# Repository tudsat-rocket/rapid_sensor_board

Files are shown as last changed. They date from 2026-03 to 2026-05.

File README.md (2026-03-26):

# Rapid Sensor Board
this module is meant to be a general-purpose amplifier which is going to be used for all analogue sensors which will be in the rocket, those include the WIKA pressure sensors as well as the fancy-fins strain gauges.

## Description
The main function of the module is to amplify signals with low voltage levels that are too small to be useful for our ADCs. Therefore the board has two sides with solder pads, one to connect to the IO board and one to connect to a sensor. The layout is designed in a way, that the sensor side is compatible with the WIKA TPR-Flex PCBs.

## Features
* Selectable gain (1-1000) -> the selection of RG1 will determine the gain (G = 1 + 49,4kOhm/RG)
* selectable offset -> output offset can either be 0V or Vcc/2
* Breakaway mounting holes
## Connections
### To IO-Board:
Connects the amplifier module with the IO-Board with the following pins:
* u+  ->  positive supply voltage (3-36V)
* u-  ->  gnd as "neg" supply voltage (only use in single supply mode) | reference for the output signal.
* o+  ->  amplified signal, references gnd (u-)
* ref  ->  selected reference signal (0V or Vcc/2) can be used to get additional information (e.g. detect noise on supply line(?))

### To sensor:
Connects the amplifier module with the Sensor with the following pins:
* u+  -> positive supply voltage (filtered supply voltage)
* u-  -> neg. supply voltage (gnd)
* s+  -> positive signal
* s-  -> negative signal

## User guideline:
The Gain resistor (RG1) must be chosen in a way that the expected maximum amplified voltage is lower than 4.85V (5V - 0.15V) and the expected minimum amplified voltage is higher than 0.1V if a smaller (or negative) output voltage is expected the solder jumper for the reference voltage needs to be connected to 3 to set an output shift.
Only if the connected sensor is expected to output a signal which exclusively results in an output signal that is in the above given values, can the reference solder jumper be set to 1.

The above-given adjustments are necessary as the IO module is only able to read values between 0V and 5V. A higher Input voltage can be used if the connected sensor needs a supply voltage which exceeds 5V. The amplified signal then still needs to be smaller than the given 4.85V.

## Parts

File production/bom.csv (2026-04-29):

Designator | Footprint | Quantity | Value | LCSC Part #
C1 | 0402 | 1 | 10u | C15525
C10, C9 | 0402 | 2 | 1n | C1523
C14, C3, C4 | 0402 | 3 | 100n | C1525
C15, C16 | 0402 | 2 | 1u | C52923
C2 | 0402 | 1 | 4u7 | C23733
C7, C8 | 0402 | 2 | 10n | C15195
D1 | D_SOD-523 | 1 | 1SS424 | C6657698
D2, D3, D7, D8 | D_SOD-523 | 4 | ESD5Z36 | C20933
D4 | D_SOD-523 | 1 | ESD5Zxx | C20933
FB1, FB2 | 0402 | 2 | 120R | C76891
IC1 | WSON-8-1EP_3x3mm_P0.5mm_EP1.2x2mm | 1 | INA826AID | C2870890
J3 | R_Axial_DIN0204_L3.6mm_D1.6mm_P1.90mm_Vertical | 1 | Conn_01x02_Socket
J5 | PinHeader_1x04_P1.27mm_Vertical | 1 | Conn_01x04_Socket
JP1 | SolderJumper-3_P1.3mm_Open_RoundedPad1.0x1.5mm | 1 | ADR1
JP2 | SolderJumper-3_P1.3mm_Open_RoundedPad1.0x1.5mm | 1 | ADR0
JP3 | SolderJumper-3_P1.3mm_Open_Pad1.0x1.5mm | 1 | SolderJumper_3_Open
R1, R2 | 0402 | 2 | 47k | C25792
R10, R9 | 0402 | 2 | 100 | C25076
R5, R6 | 0402 | 2 | 10k | C25744
TP1 | TestPoint_Pad_D1.5mm | 1 | TestPoint
U2 | SOT-23-5 | 1 | MCP6001-OT | C116490
U3 | SOT-23-5 | 1 | MIC5504-3.3YM5 | C3021093
U4 | VSSOP-8_3x3mm_P0.65mm | 1 | ADC101C021CIMM | C1543337

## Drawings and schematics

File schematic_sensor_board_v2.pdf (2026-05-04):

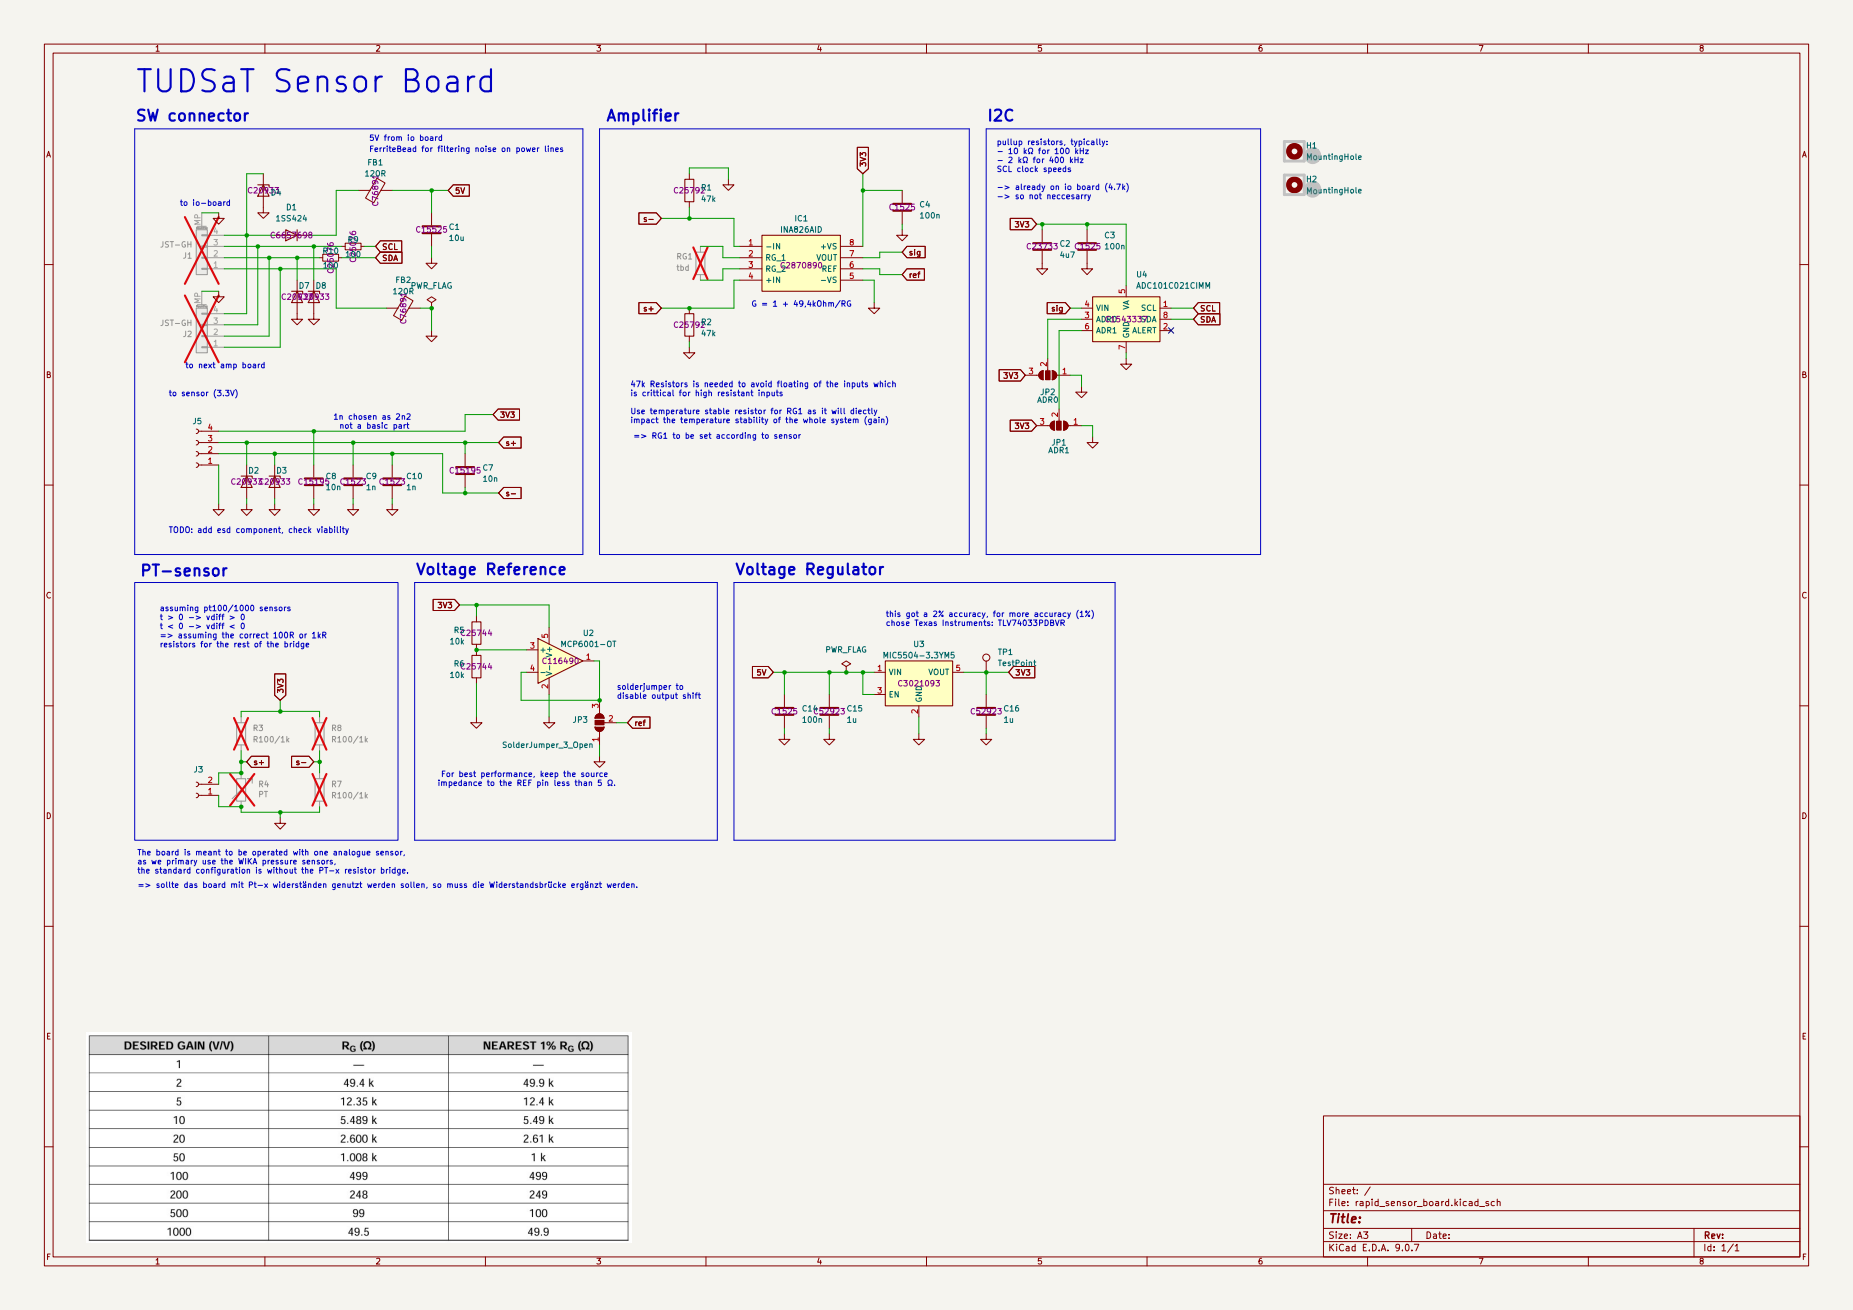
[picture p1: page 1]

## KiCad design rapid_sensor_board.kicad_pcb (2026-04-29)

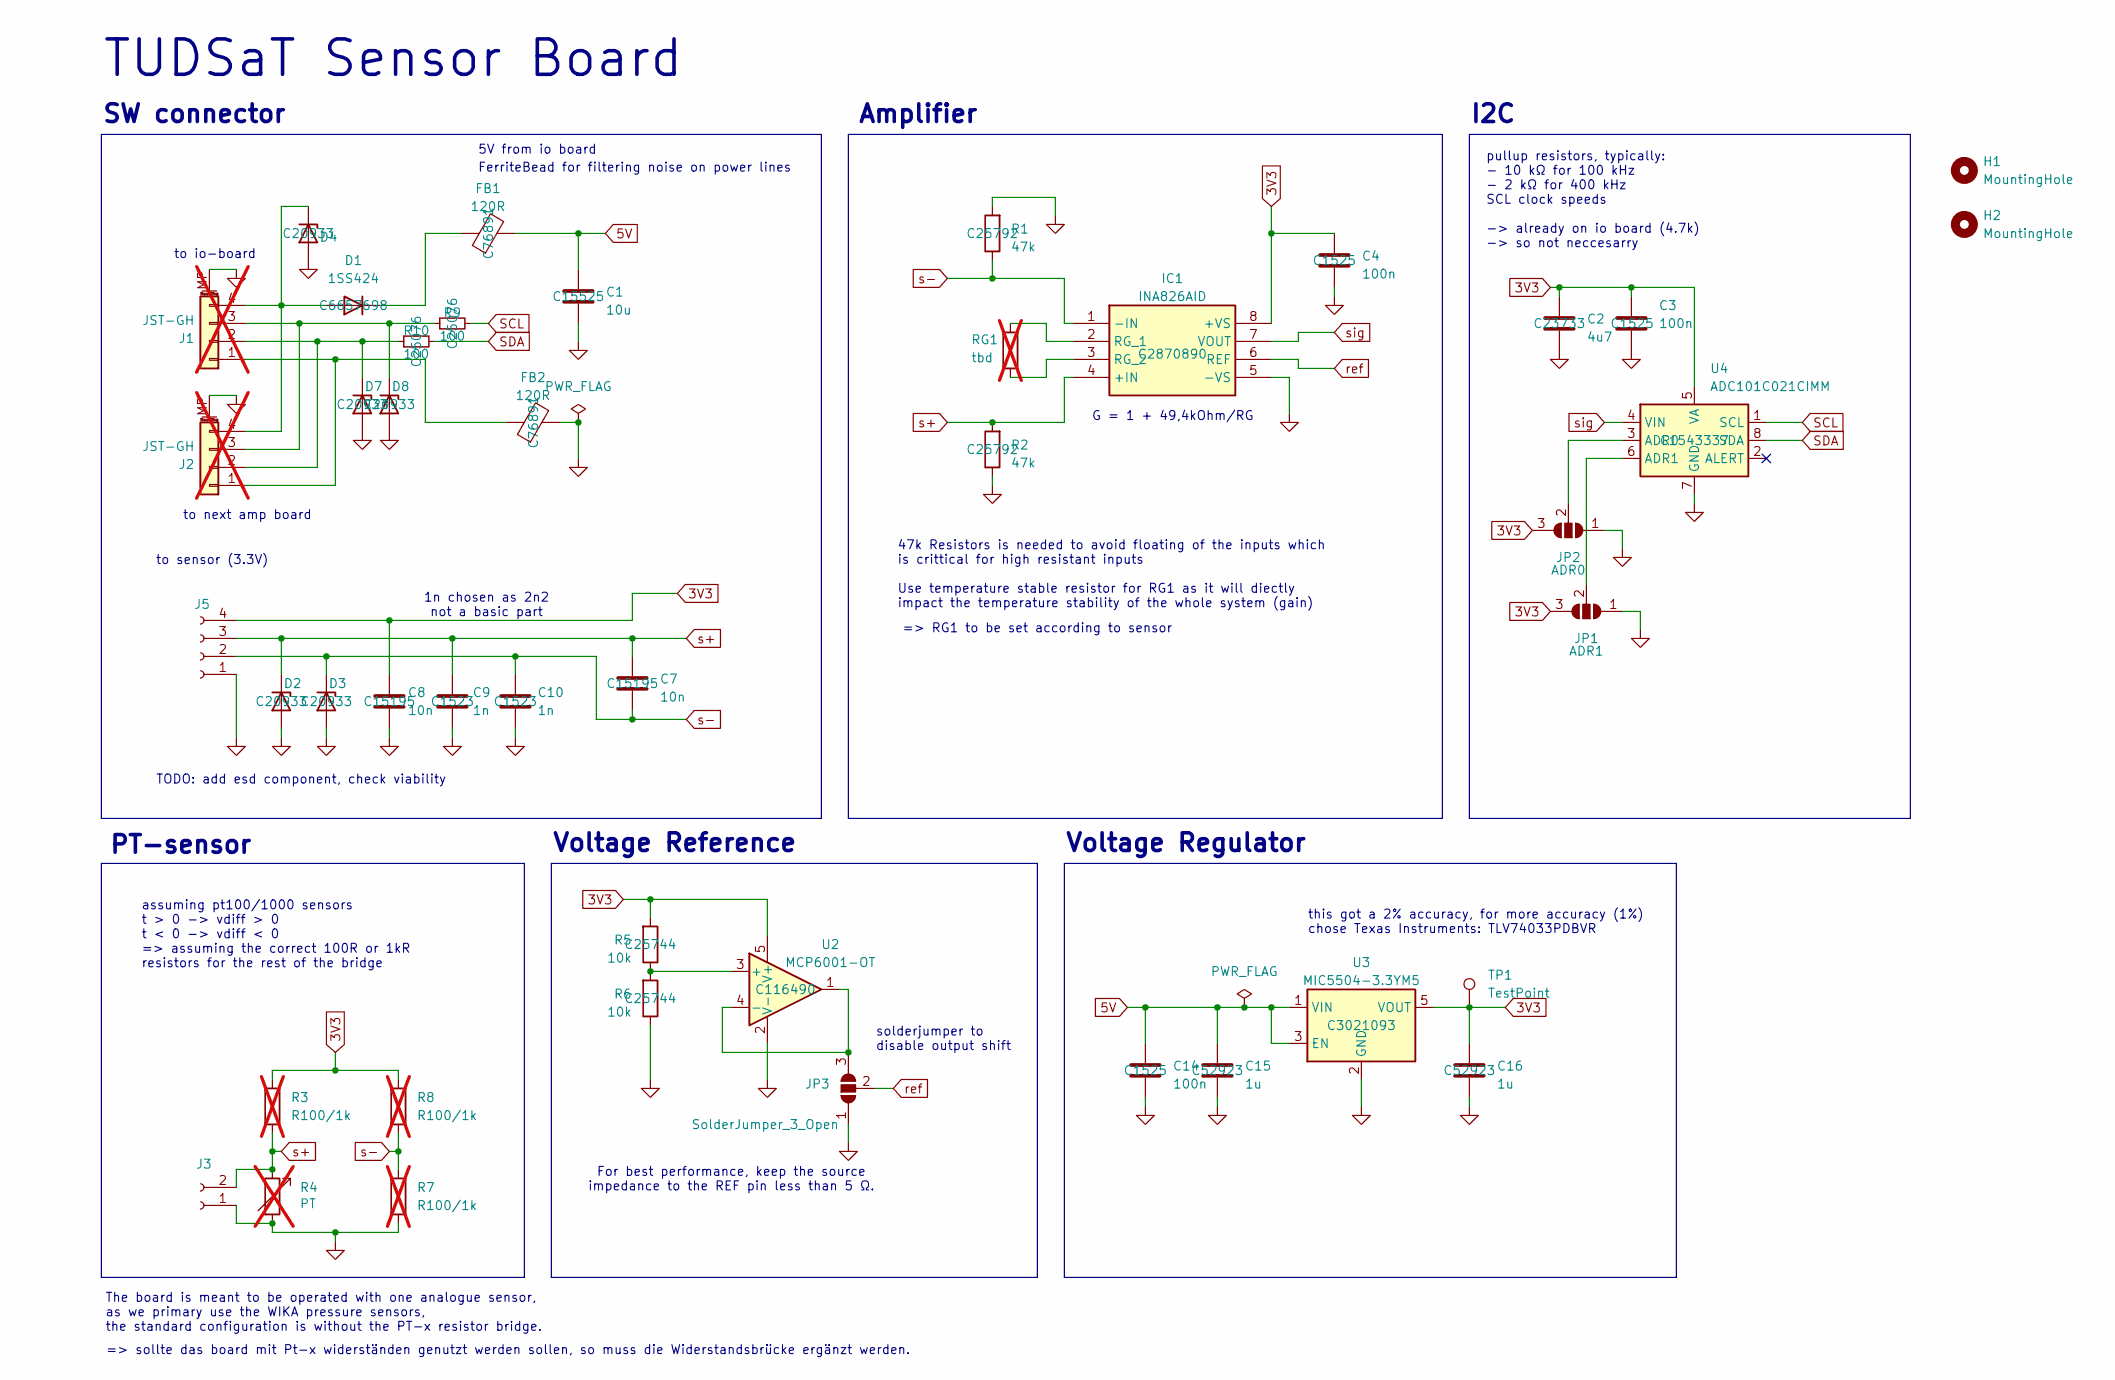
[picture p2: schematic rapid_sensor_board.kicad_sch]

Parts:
C1: 10u; C_0402_1005Metric; LCSC C15525
C2: 4u7; C_0402_1005Metric; LCSC C23733
C3, C4, C14: 100n; C_0402_1005Metric; LCSC C1525
C7, C8: 10n; C_0402_1005Metric; LCSC C15195
C9, C10: 1n; C_0402_1005Metric; LCSC C1523
C15, C16: 1u; C_0402_1005Metric; LCSC C52923
D1: 1SS424; D_SOD-523; LCSC C6657698
D2, D3, D7, D8: ESD5Z36; D_SOD-523; LCSC C20933
D4: ESD5Zxx; D_SOD-523; LCSC C20933
FB1, FB2: 120R; L_0402_1005Metric; LCSC C76891
H1, H2: MountingHole; MountingHole_2.2mm_M2_DIN965_Pad
IC1: INA826AID; WSON-8-1EP_3x3mm_P0.5mm_EP1.2x2mm; Mouser Part Number 595-INA826AID
J1, J2: JST-GH; JST_GH_SM04B-GHS-TB_1x04-1MP_P1.25mm_Horizontal; Part# BM04B-GHS-TBT; LCSC C161692; not fitted
J3: Conn_01x02_Socket; R_Axial_DIN0204_L3.6mm_D1.6mm_P1.90mm_Vertical
J5: Conn_01x04_Socket; PinHeader_1x04_P1.27mm_Vertical
JP1: ADR1; SolderJumper-3_P1.3mm_Open_RoundedPad1.0x1.5mm
JP2: ADR0; SolderJumper-3_P1.3mm_Open_RoundedPad1.0x1.5mm
JP3: SolderJumper_3_Open; SolderJumper-3_P1.3mm_Open_Pad1.0x1.5mm
R1: 47k; R_0402_1005Metric; LCSC C25792
R2: 47k; R_0402_1005Metric_Pad0.72x0.64mm_HandSolder; LCSC C25792
R3, R7, R8: R100/1k; R_0805_2012Metric_Pad1.20x1.40mm_HandSolder; not fitted
R4: PT; not fitted
R5, R6: 10k; R_0402_1005Metric_Pad0.72x0.64mm_HandSolder; LCSC C25744
R9, R10: 100; R_0402_1005Metric; LCSC C25076
RG1: tbd; R_1206_3216Metric_Pad1.30x1.75mm_HandSolder; not fitted
TP1: TestPoint; TestPoint_Pad_D1.5mm
U2: MCP6001-OT; SOT-23-5; LCSC C116490
U3: MIC5504-3.3YM5; SOT-23-5; LCSC C3021093
U4: ADC101C021CIMM; VSSOP-8_3x3mm_P0.65mm; LCSC C1543337

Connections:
3V3: C2.1, C3.1, C4.1, C8.1, C16.1, IC1.8 (+VS), J5.4, JP1.3 (B), JP2.3 (B), R3.1, R5.2, R8.1, TP1.1, U2.5 (V+), U3.5 (VOUT), U4.5 (VA)
5V: C1.1, C14.1, C15.1, FB1.2, U3.1 (VIN), U3.3 (EN)
GND: C1.2, C2.2, C3.2, C4.2, C8.2, C9.2, C10.2, C14.2, C15.2, C16.2, D2.2 (A), D3.2 (A), D4.2 (A), D7.2 (A), D8.2 (A), FB2.2, IC1.5 (-VS), J1.MP (MountPin), J2.MP (MountPin), J3.1, J5.1, JP1.1 (A), JP2.1 (A), JP3.1 (A), R1.2, R2.1, R4.2, R6.1, R7.2, U2.2 (V-), U3.2 (GND), U4.7 (GND)
unnamed: D1.2 (A), D4.1 (K), J1.4, J2.4
unnamed: D1.1 (K), FB1.1
unnamed: D7.1 (K), J1.2, J2.2, R10.1
unnamed: D8.1 (K), J1.3, J2.3, R9.1
unnamed: IC1.2 (RG_1), RG1.2
unnamed: IC1.3 (RG_2), RG1.1
unnamed: FB2.1, J1.1, J2.1
unnamed: JP1.2 (C), U4.6 (ADR1)
unnamed: JP2.2 (C), U4.3 (ADR0)
unnamed: JP3.3 (B), U2.1, U2.4 (-)
unnamed: R5.1, R6.2, U2.3 (+)
SCL: R9.2, U4.1 (SCL)
SDA: R10.2, U4.8 (SDA)
ref: IC1.6 (REF), JP3.2 (C)
s+: C7.1, C9.1, D2.1 (K), IC1.4 (+IN), J3.2, J5.3, R2.2, R3.2, R4.1
s-: C7.2, C10.1, D3.1 (K), IC1.1 (-IN), J5.2, R1.1, R7.1, R8.2
sig: IC1.7 (VOUT), U4.4 (VIN)

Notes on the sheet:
pullup resistors, typically: - 10 kΩ for 100 kHz - 2 kΩ for 400 kHz SCL clock speeds -> already on io board (4.7k) -> so not neccesarry
to sensor (3.3V)
G = 1 + 49,4kOhm/RG
SW connector
Voltage Regulator
to next amp board
The board is meant to be operated with one analogue sensor, as we primary use the WIKA pressure sensors, the standard configuration is without the PT-x resistor bridge.
=> sollte das board mit Pt-x widerständen genutzt werden sollen, so muss die Widerstandsbrücke ergänzt werden.
TODO: add esd component, check viability
5V from io board
FerriteBead for filtering noise on power lines
solderjumper to disable output shift
1n chosen as 2n2 not a basic part
TUDSaT Sensor Board
Voltage Reference
47k Resistors is needed to avoid floating of the inputs which is crittical for high resistant inputs Use temperature stable resistor for RG1 as it will diectly impact the temperature stability of the whole system (gain)
I2C
assuming pt100/1000 sensors t > 0 -> vdiff > 0 t < 0 -> vdiff < 0 => assuming the correct 100R or 1kR resistors for the rest of the bridge
Amplifier
PT-sensor
this got a 2% accuracy, for more accuracy (1%) chose Texas Instruments: TLV74033PDBVR
to io-board
For best performance, keep the source impedance to the REF pin less than 5 Ω.
=> RG1 to be set according to sensor

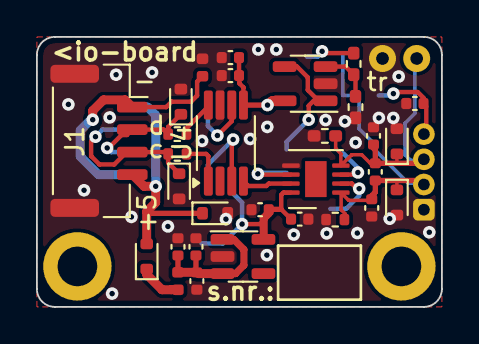
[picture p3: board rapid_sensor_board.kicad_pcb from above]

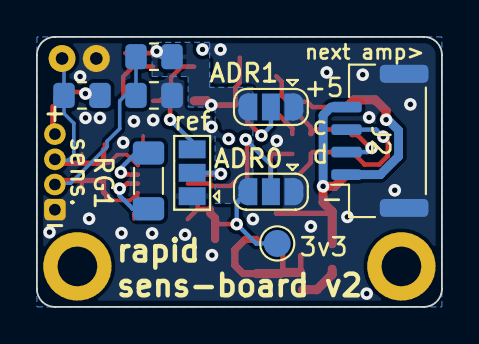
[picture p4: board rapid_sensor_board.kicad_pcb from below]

Board: 4 copper layers, 22.5 x 15.0 mm, 43 parts (9 on the bottom side), 20 nets.

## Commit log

2026-03-26 added lcsc numbers
    [frodo_amplifier_module.kicad_pcb, frodo_amplifier_module.kicad_sch]
2026-03-26 Rename module to Rapid Sensor Board
    Updated the module name and clarified its purpose.
2026-04-29 some changes, added production files
    [bom.csv, designators.csv, frodo_amplifier_module.kicad_pcb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]
